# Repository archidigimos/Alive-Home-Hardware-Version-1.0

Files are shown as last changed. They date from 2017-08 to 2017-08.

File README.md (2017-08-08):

# Alive-Home-Hardware-Version-1.0
Eagle schematics and Board files for the Initial version of Alive Home automation product. This version of product is powered by an Atmega MCU and is customised to be installed in Meghnad Saha Hall of Residence, IIT Kharagpur.
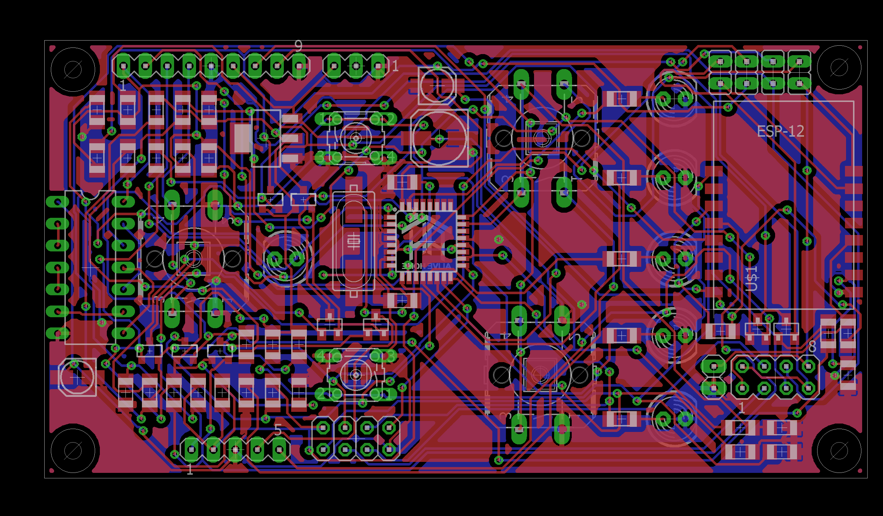
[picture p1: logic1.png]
Logic board to control fan and switching boards

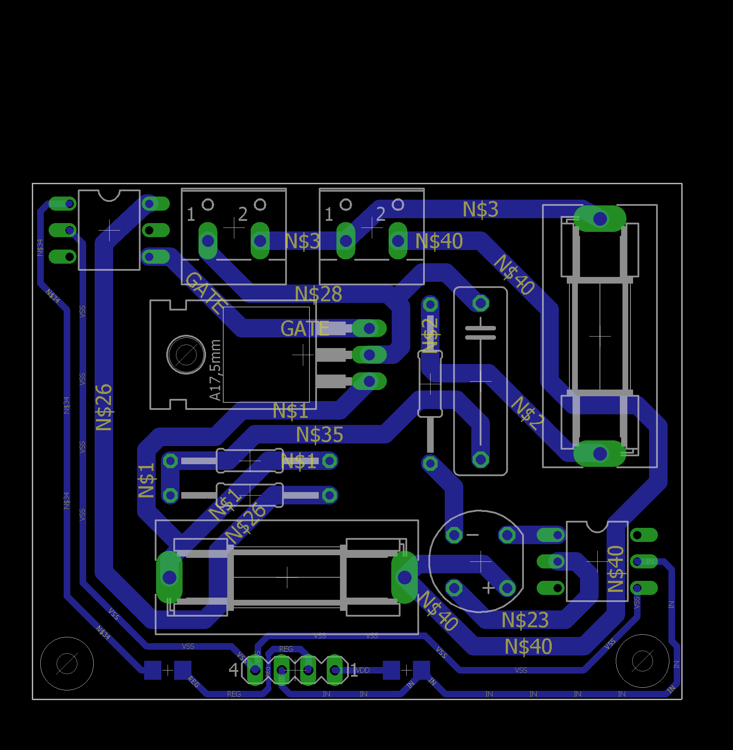
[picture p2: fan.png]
AC Fan control board

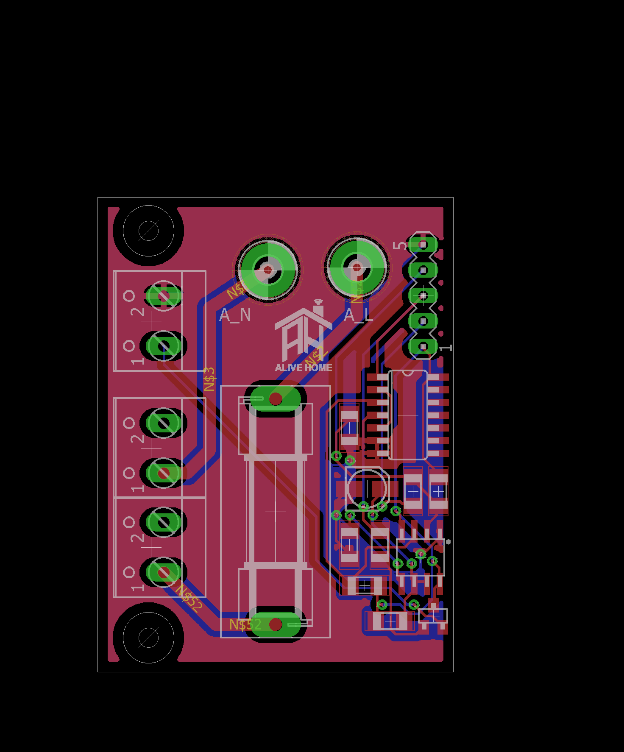
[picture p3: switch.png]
AC appliance switching Board


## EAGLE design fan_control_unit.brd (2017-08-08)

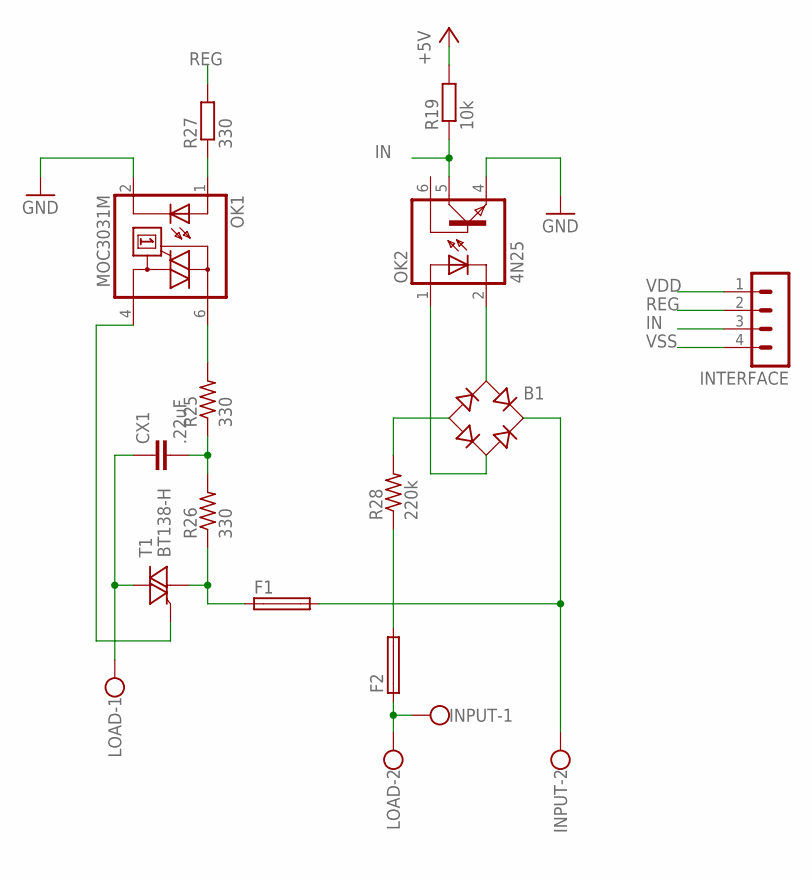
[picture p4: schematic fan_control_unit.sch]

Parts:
B1: RB1A
CX1: .22uF; C150-054X183
F1, F2: SH22,5A
INPUT: W237-102
INTERFACE: MA04-1
LOAD: W237-102
OK1: MOC3031M; DIL06
OK2: 4N25; DIL06
R19: 10k; R1206
R25, R26: 330; 0207/15
R27: 330; R1206
R28: 220k; 0207/15
T1: BT138-H; TO220BH

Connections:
GATE: OK1.4 (A1), T1.G
IN: INTERFACE.3, OK2.5 (COL), R19.1
unnamed: F1.1, R26.1, T1.T1 (A1)
unnamed: F2.2, R28.1
unnamed: F2.1, INPUT.1, LOAD.2
unnamed: B1.AC1, OK2.2 (C)
unnamed: B1.AC2, OK2.1 (A)
unnamed: OK1.6 (A2), R25.2
unnamed: CX1.1, LOAD.1, T1.T2 (A2)
unnamed: OK1.1 (A), R27.1
unnamed: CX1.2, R25.1, R26.2
unnamed: B1.-, R28.2
unnamed: B1.+, F1.2, INPUT.2
REG: INTERFACE.2, R27.2
VDD: INTERFACE.1, R19.2
VSS: INTERFACE.4, OK1.2 (C), OK2.4 (EMI)

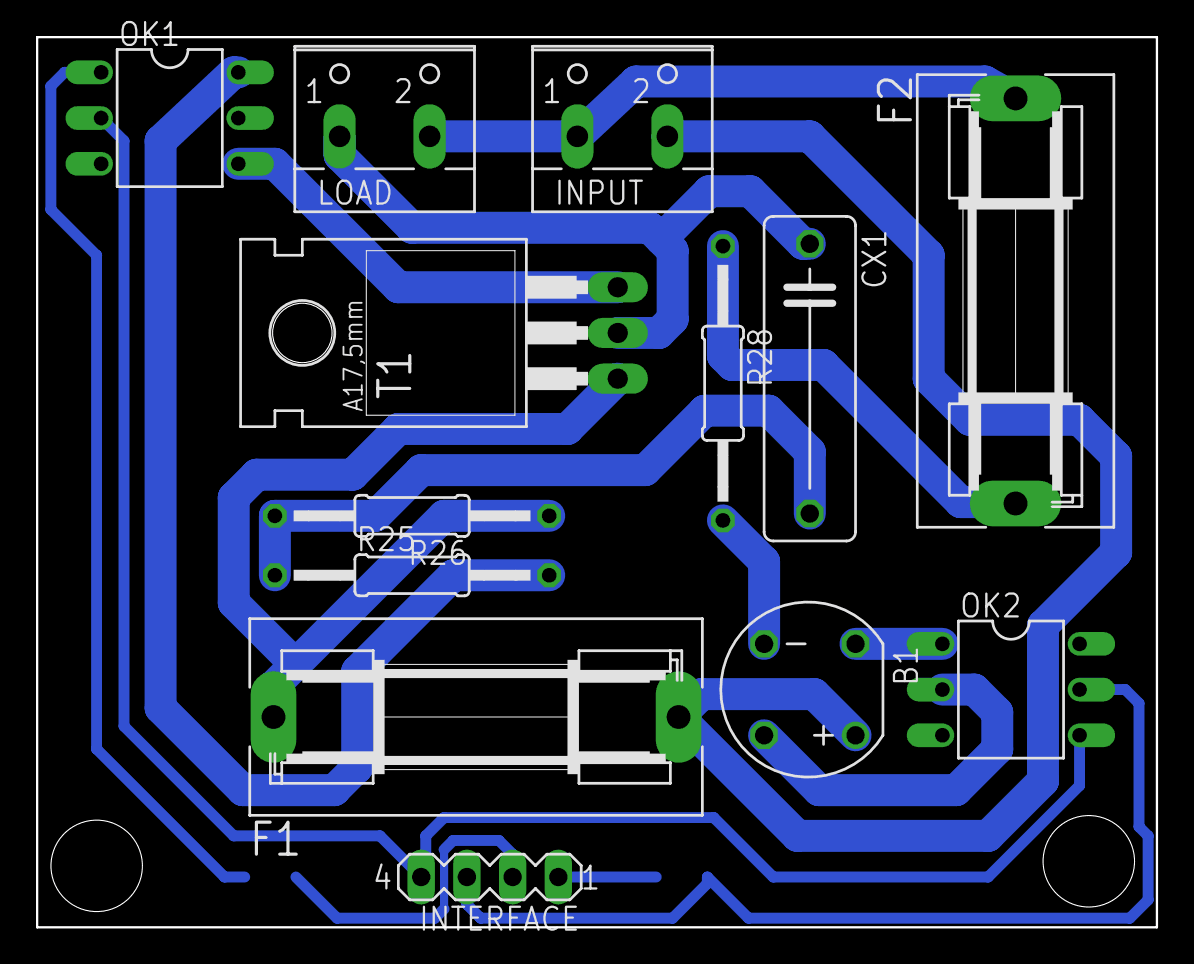
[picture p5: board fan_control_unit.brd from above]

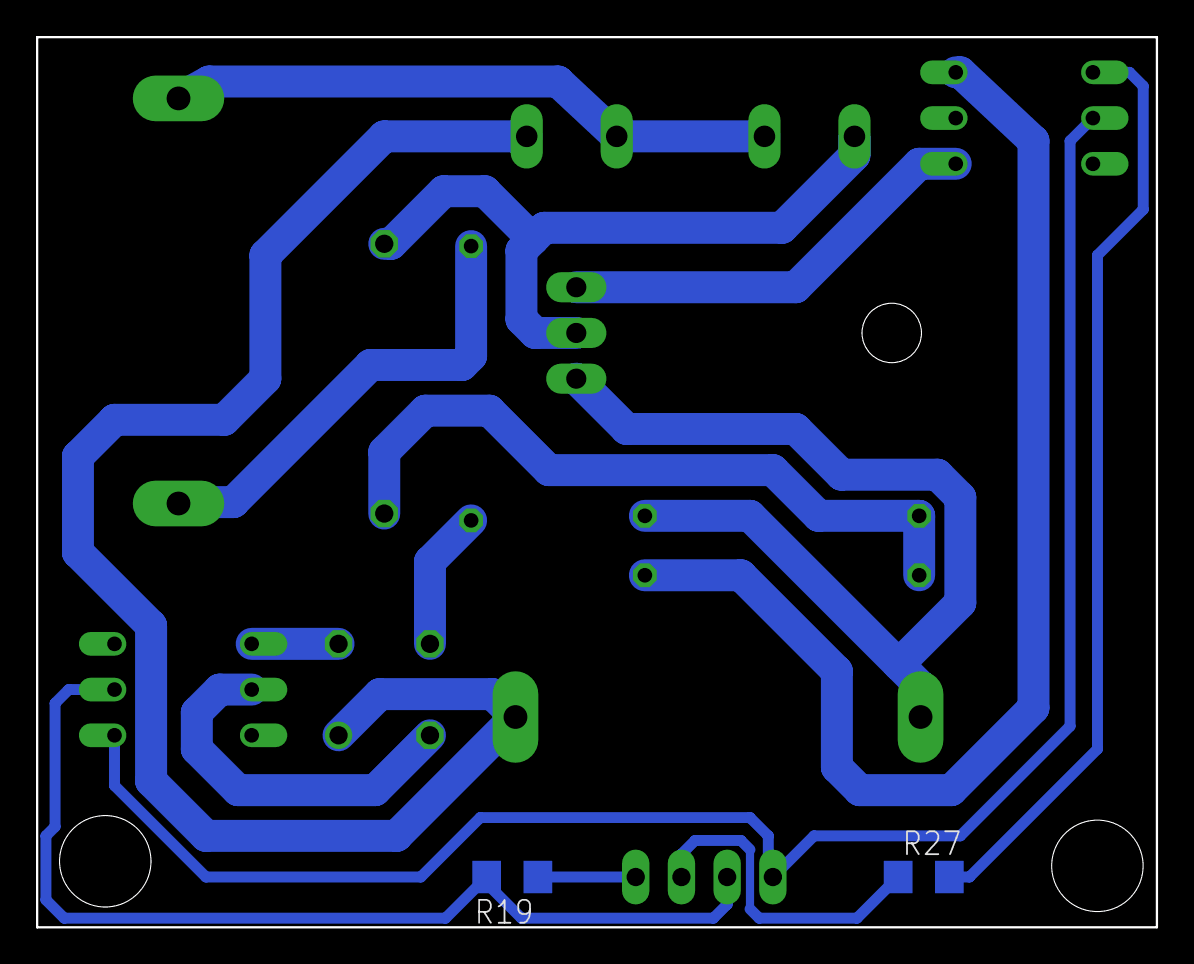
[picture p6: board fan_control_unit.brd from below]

Board: 2 copper layers, 62.2 x 49.5 mm, 15 parts (2 on the bottom side), 16 nets.

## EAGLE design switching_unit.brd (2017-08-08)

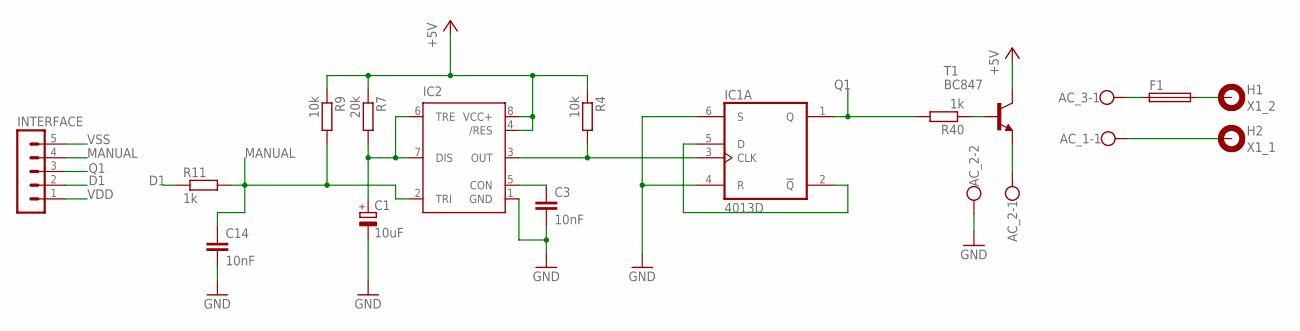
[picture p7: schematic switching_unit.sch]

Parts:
AC_1, AC_2, AC_3: W237-102
C1: 10uF; 153CLV-0405
C3, C14: 10nF; C1206
F1: SH22,5A
H1: X1_2; 2,8-PAD
H2: X1_1; 2,8-PAD
IC1: 4013D; SO14
IC2: NE555D; SO08
INTERFACE: MA05-1
R4, R9: 10k; R1206
R7: 20k; R1206
R11, R40: 1k; R1206
T1: BC847; SOT23

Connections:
D1: INTERFACE.2, R11.1
MANUAL: C14.1, IC2.2 (TRI), INTERFACE.4, R9.2, R11.2
unnamed: R40.1, T1.1 (B)
unnamed: F1.2, H1.B2,8
unnamed: AC_1.1, H2.B2,8
unnamed: AC_2.1, T1.2 (E)
unnamed: IC1.2 (!Q), IC1.5 (D)
unnamed: IC1.3 (CLK), IC2.3 (OUT), R4.2
unnamed: C1.+, IC2.6 (TRE), IC2.7 (DIS), R7.2
unnamed: C3.1, IC2.5 (CON)
unnamed: AC_3.1, F1.1
Q1: IC1.1 (Q), INTERFACE.3, R40.2
VDD: IC1.14 (VDD), IC2.4 (/RES), IC2.8 (VCC+), INTERFACE.1, R4.1, R7.1, R9.1, T1.3 (C)
VSS: AC_2.2, C1.-, C3.2, C14.2, IC1.4 (R), IC1.6 (S), IC1.7 (VSS), IC2.1 (GND), INTERFACE.5

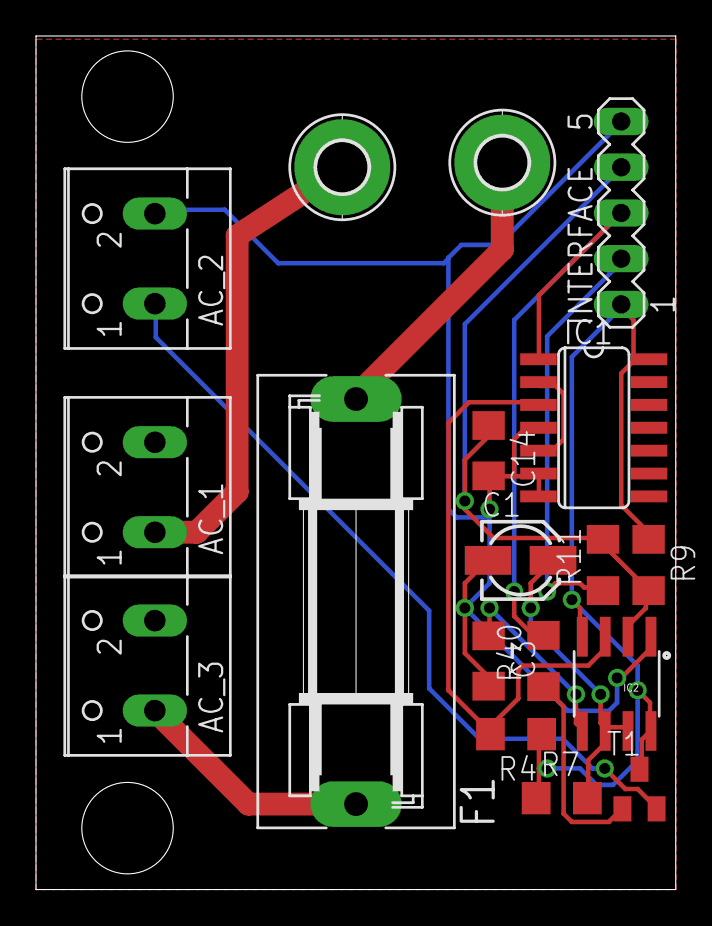
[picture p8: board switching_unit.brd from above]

Board: 2 copper layers, 35.5 x 47.4 mm, 18 parts (0 on the bottom side), 14 nets.

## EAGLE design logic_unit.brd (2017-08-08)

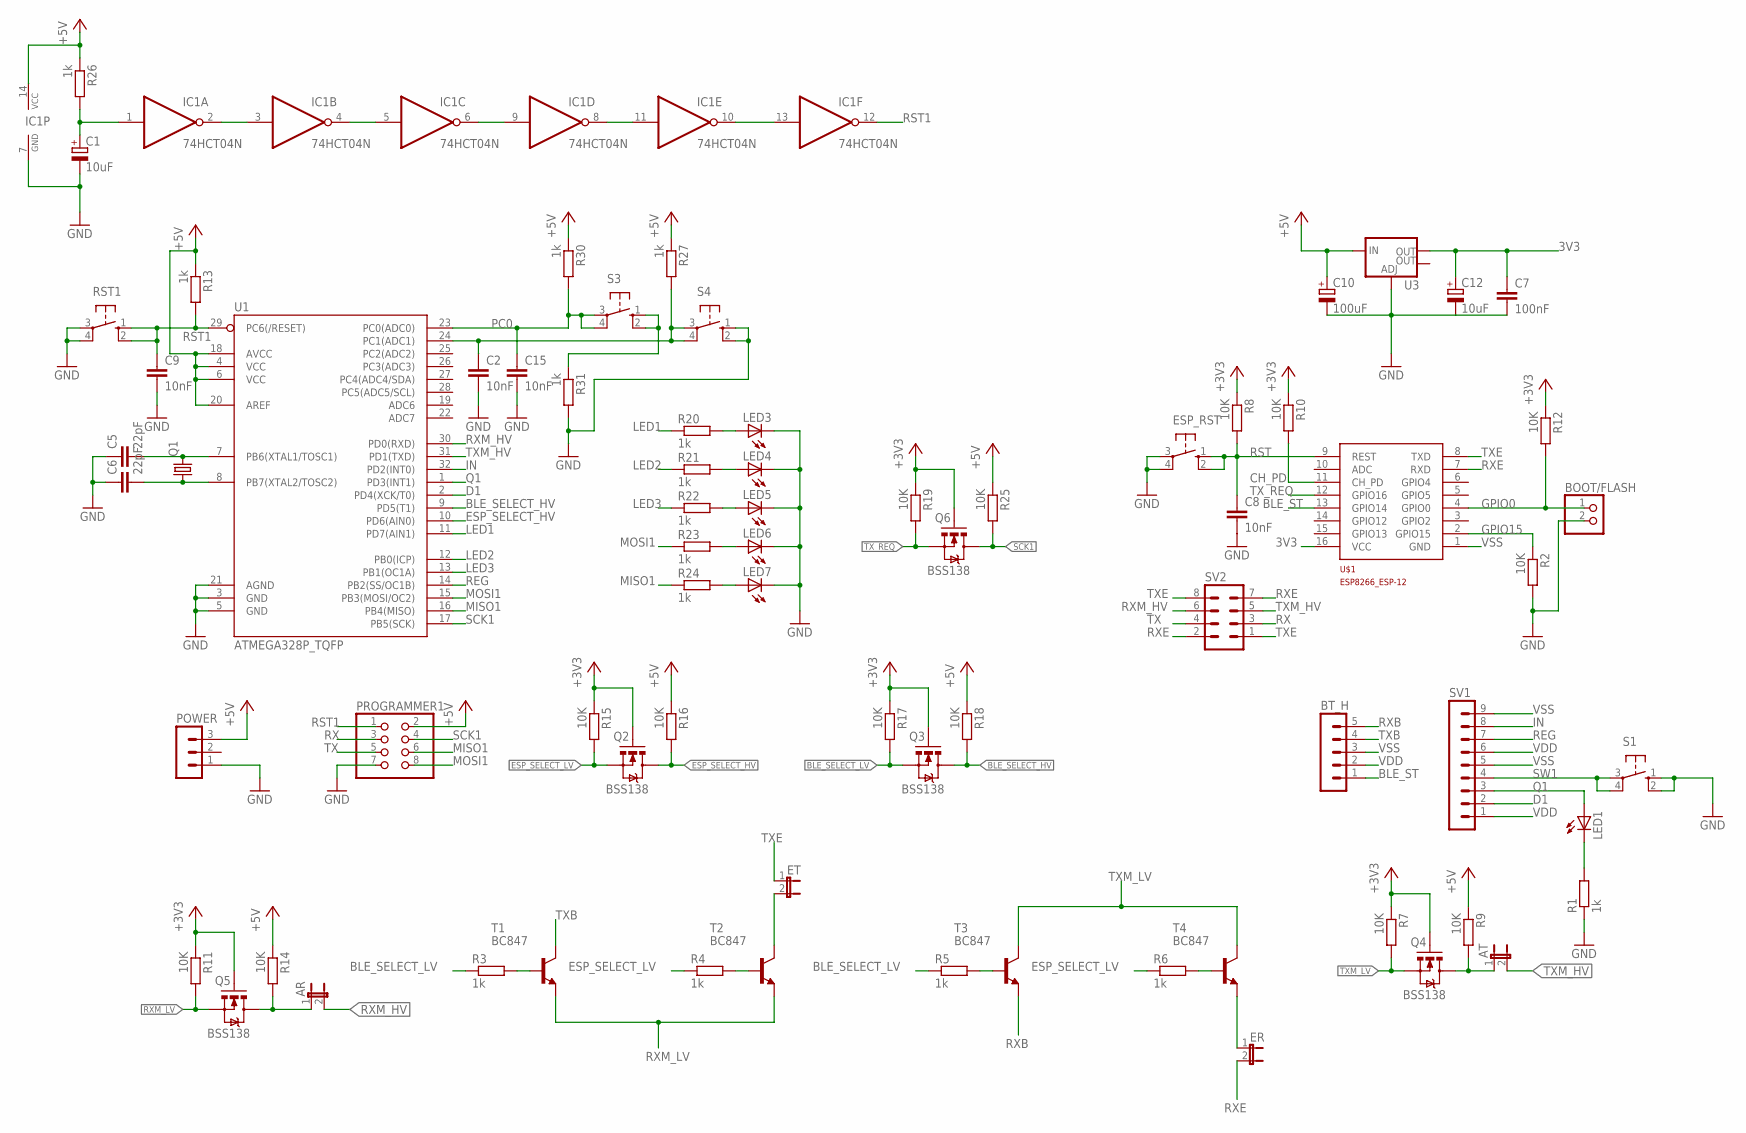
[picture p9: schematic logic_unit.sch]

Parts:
AR: JP1E; JP1
AT: JP1E; JP1
BOOT/FLASH: PINHD-1X2; 1X02
BT_H: MA05-1
C1, C12: 10uF; 153CLV-0405
C2, C8, C9, C15: 10nF; C1206
C5, C6: 22pF; C1206
C7: 100nF; C1206
C10: 100uF; 153CLV-0605
ER: JP1E; JP1
ESP_RST: 10-XX; B3F-10XX
ET: JP1E; JP1
IC1: 74HCT04N; DIL14
LED1, LED3, LED4, LED5, LED6, LED7: LED5MM
POWER: MA03-1
PROGRAMMER1: PINHD-2X4; 2X04
Q1: CRYSTALHC49UP; HC49UP
Q2, Q3, Q4, Q5, Q6: BSS138; SOT23-3
R1, R3, R4, R5, R6, R13, R20, R21, R22, R23, R24, R26, R27, R30, R31: 1k; R1206
R2, R7, R8, R9, R10, R11, R12, R14, R15, R16, R17, R18, R19, R25: 10K; R1206
RST1: 10-XX; B3F-10XX
S1, S3, S4: 40-XX; B3F-40XX
SV1: MA09-1
SV2: MA04-2
T1, T2, T3, T4: BC847; SOT23
U1: ATMEGA328P_TQFP; TQFP32-08
U3: V_REG_LM1117SOT223; SOT223
U$1: ESP8266_ESP-12; ESP8266-ESP12

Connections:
3V3: C7.1, C12.+, Q2.1 (G), Q3.1 (G), Q4.1 (G), Q5.1 (G), Q6.1 (G), R7.1, R8.1, R10.1, R11.1, R12.1, R15.1, R17.1, R19.1, U3.2 (OUT), U$1.16 (VCC)
BLE_SELECT_HV: Q3.3 (D), R18.2, U1.9 (PD5(T1))
BLE_SELECT_LV: Q3.2 (S), R3.1, R5.1, R17.2
BLE_ST: BT_H.1, U$1.13 (GPIO14)
CH_PD: R10.2, U$1.11 (CH_PD)
D1: SV1.2, U1.2 (PD4(XCK/T0))
ESP_SELECT_HV: Q2.3 (D), R16.2, U1.10 (PD6(AIN0))
ESP_SELECT_LV: Q2.2 (S), R4.1, R6.1, R15.2
GPIO0: BOOT/FLASH.1, R12.2, U$1.4 (GPIO0)
GPIO15: R2.1, U$1.2 (GPIO15)
IN: SV1.8, U1.32 (PD2(INT0))
LED1: R20.1, U1.11 (PD7(AIN1))
LED2: R21.1, U1.12 (PB0(ICP))
LED3: R22.1, U1.13 (PB1(OC1A))
MISO1: PROGRAMMER1.6, R24.1, U1.16 (PB4(MISO))
MOSI1: PROGRAMMER1.8, R23.1, U1.15 (PB3(MOSI/OC2))
unnamed: R3.2, T1.1 (B)
unnamed: R4.2, T2.1 (B)
unnamed: R5.2, T3.1 (B)
unnamed: IC1.2 (O), IC1.3 (I)
unnamed: LED1.K (C), R1.2
unnamed: R6.2, T4.1 (B)
unnamed: IC1.4 (O), IC1.5 (I)
unnamed: IC1.6 (O), IC1.9 (I)
unnamed: IC1.8 (O), IC1.11 (I)
unnamed: IC1.10 (O), IC1.13 (I)
unnamed: C1.+, IC1.1 (I), R26.2
unnamed: C5.2, Q1.2, U1.7 (PB6(XTAL1/TOSC1))
unnamed: C2.1, R27.2, S4.3, S4.4 (P1), U1.24 (PC1(ADC1))
unnamed: C6.2, Q1.1, U1.8 (PB7(XTAL2/TOSC2))
unnamed: LED3.A, R20.2
unnamed: LED4.A, R21.2
unnamed: LED5.A, R22.2
unnamed: LED6.A, R23.2
unnamed: LED7.A, R24.2
unnamed: R31.1, S3.1 (S), S3.2 (S1)
PC0: C15.1, R30.2, S3.3, S3.4 (P1), U1.23 (PC0(ADC0))
Q1: LED1.A, SV1.3, U1.1 (PD3(INT1))
REG: SV1.7, U1.14 (PB2(SS/OC1B))
RST: C8.1, ESP_RST.1 (S), ESP_RST.2 (S1), R8.2, U$1.9 (REST)
RST1: C9.1, IC1.12 (O), PROGRAMMER1.1, R13.2, RST1.1 (S), RST1.2 (S1), U1.29 (PC6(/RESET))
RX: PROGRAMMER1.3, SV2.3
RXB: BT_H.5, T3.2 (E)
RXE: ER.2, SV2.2, SV2.7, U$1.7 (RXD)
RXE_J: ER.1, T4.2 (E)
RXM_HV: AR.2, SV2.6, U1.30 (PD0(RXD))
RXM_HV_J: AR.1, Q5.3 (D), R14.2
RXM_LV: Q5.2 (S), R11.2, T1.2 (E), T2.2 (E)
SCK1: PROGRAMMER1.4, Q6.3 (D), R25.2, U1.17 (PB5(SCK))
SW1: S1.3, S1.4 (P1), SV1.4
TX: PROGRAMMER1.5, SV2.4
TXB: BT_H.4, T1.3 (C)
TXE: ET.1, SV2.1, SV2.8, U$1.8 (TXD)
TXE_J: ET.2, T2.3 (C)
TXM_HV: AT.2, SV2.5, U1.31 (PD1(TXD))
TXM_HV_J: AT.1, Q4.3 (D), R9.2
TXM_LV: Q4.2 (S), R7.2, T3.3 (C), T4.3 (C)
TX_REQ: Q6.2 (S), R19.2, U$1.12 (GPIO16)
VDD: BT_H.2, C10.+, IC1.14 (VCC), POWER.3, PROGRAMMER1.2, R9.1, R13.1, R14.1, R16.1, R18.1, R25.1, R26.1, R27.1, R30.1, SV1.1, SV1.6, U1.4 (VCC), U1.6 (VCC), U1.18 (AVCC), U1.20 (AREF), U3.3 (IN)
VSS: BOOT/FLASH.2, BT_H.3, C1.-, C2.2, C5.1, C6.1, C7.2, C8.2, C9.2, C10.-, C12.-, C15.2, ESP_RST.3, ESP_RST.4 (P1), IC1.7 (GND), LED3.K (C), LED4.K (C), LED5.K (C), LED6.K (C), LED7.K (C), POWER.1, PROGRAMMER1.7, R1.1, R2.2, R31.2, RST1.3, RST1.4 (P1), S1.1 (S), S1.2 (S1), S4.1 (S), S4.2 (S1), SV1.5, SV1.9, U1.3 (GND), U1.5 (GND), U1.21 (AGND), U3.1 (ADJ), U$1.1 (GND)

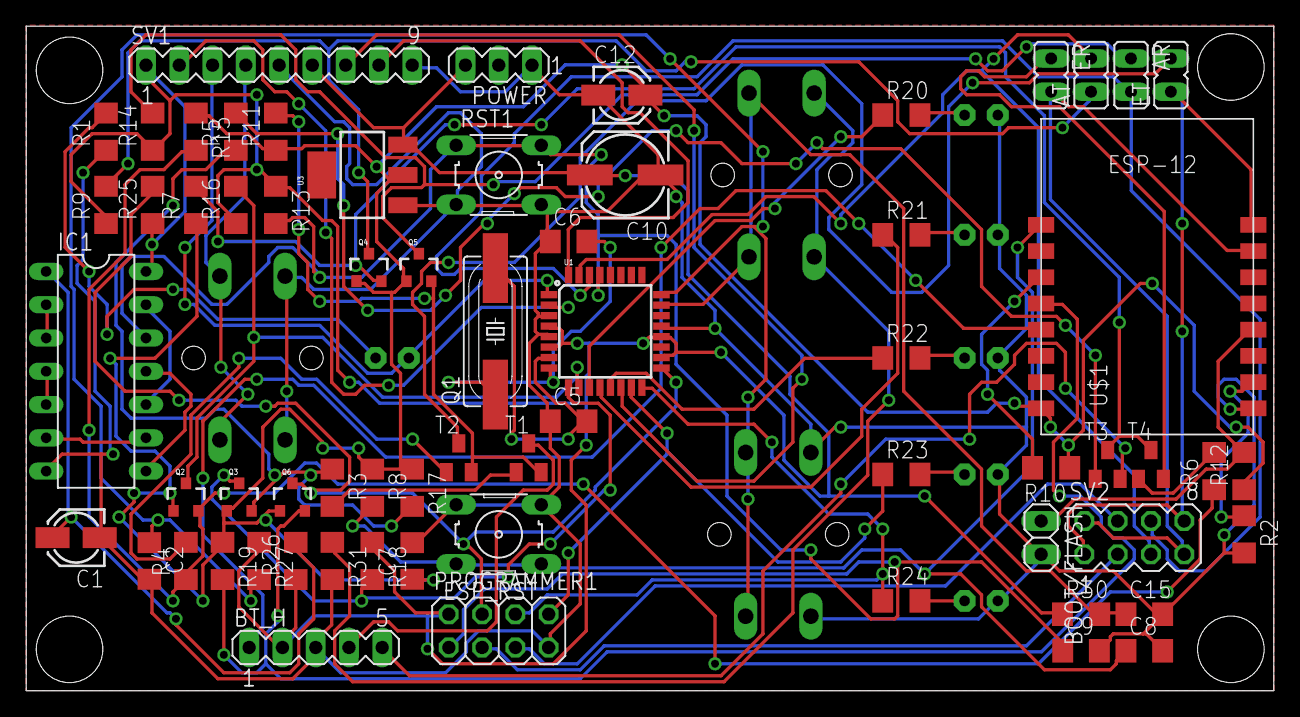
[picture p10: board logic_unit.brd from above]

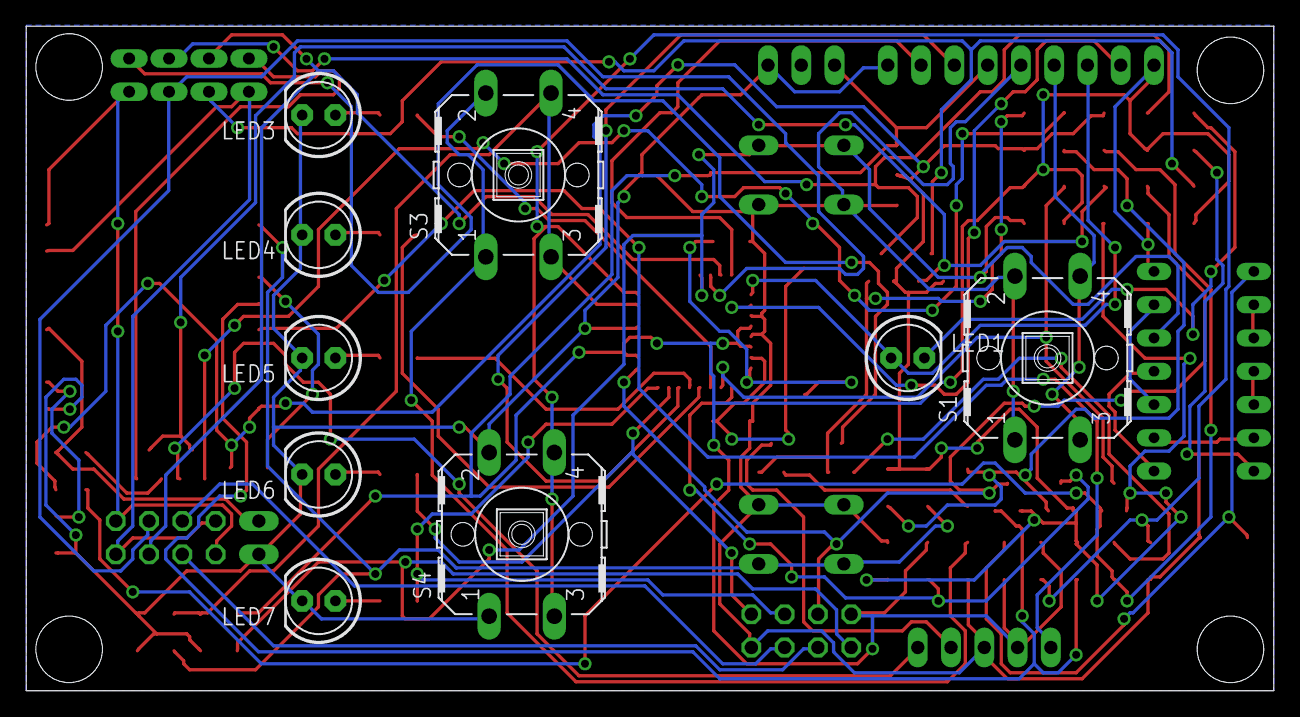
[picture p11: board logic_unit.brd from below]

Board: 2 copper layers, 95.2 x 50.7 mm, 74 parts (9 on the bottom side), 60 nets.

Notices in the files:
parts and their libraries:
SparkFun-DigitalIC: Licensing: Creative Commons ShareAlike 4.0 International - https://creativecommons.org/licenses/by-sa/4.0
